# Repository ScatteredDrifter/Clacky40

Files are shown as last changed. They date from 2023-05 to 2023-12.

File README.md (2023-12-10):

# Clacky40: 

Yet another replacement Board for the Daisy40. 
Running with a RP2040, adapted from elmos:Dizzy40

--- 
## Status:
- PCB tested, _Vial support available_, working
- compatible with Case!
- minor issue with footprint fixed, pcb is fully functional now

## Features:
- RP2040 
- _(TODO) ZMK support_
- VIAL / QMK support
- supports two encoders
- additional layout options
- additional pinouts for additional LEDS ( 5V+, GND, GPIO)

--- 

## Layouting:
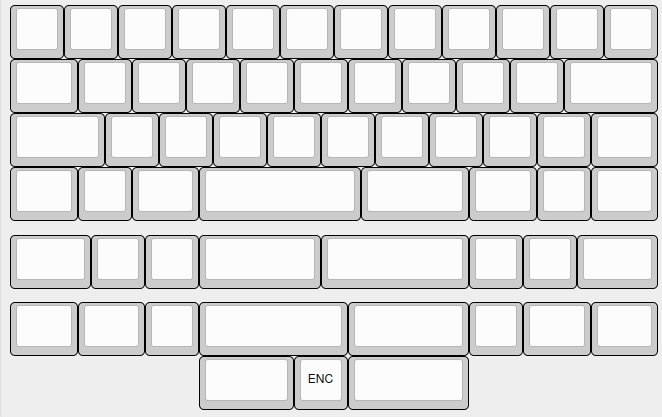
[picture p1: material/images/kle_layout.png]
image of available layouts


## Firmware:
pre-compiled file for vial can be found in the **"/firmware"** section.
To enter the bootloader - which is necessary in order to flash a new firmware - press both buttons on the back while its plugged into your computer. It should show up as a regular usb-stick in your file explorer now and you can drag the .utf onto this usb-stick. Once done it will restart and use your newly flashed firmware!
You can confirm that everything went well by opening Vial or listing the available usb-devices (`lsusb` in lin)

**Alternatively** one could download my fork of vial-qmk [here](https://github.com/ScatteredDrifter/vial-qmk) and compile the firmware themself.
For that you will have to:
1. have set up qmk and be ready to compile and flash. ( See `qmk setup` or consult [the qmk tutorial](https://docs.qmk.fm/#/newbs))
2. **find my** keyboards,  under `../keyboards/scattereddrifter/*` and choose **clacky40**.
3. make your changes
4. compile with `qmk compile --kb scattereddrifter/clacky40 --km yourKeyMap` 

### Getting PCBs:

Gathering PCBs is fairly simple, at least with JLCPCB ( which I usually default to and base my workflow around).
under the `/production/*` section you can find a zip-archive that contains the required gerber for the newest version of this board. 

1. upload the `*_gerber.zip` to JLCs website and select your prefered parameters ( pcb color, etc)
2. select "assembly" if you want to order this pcb **fully assembled with MCU etc** 
3. you will now have to supply the _positions_ and _bom (bill of materials)_ as **.csv**. You can find those at `/production/assembly/*` and should then upload them accordingly.
4. check whether every component is selected in the BOM-overview ( pinouts like J1 to Jx or keyswitches are listed but dont require any component, you can leave them out so to say)
5. finally confirm placement of the selected components ( usually I have them correct them anyway so its more or less a _sanity check_)
6. you have now ordered pcbs successfully

## Images:

### | Images of PCB | 

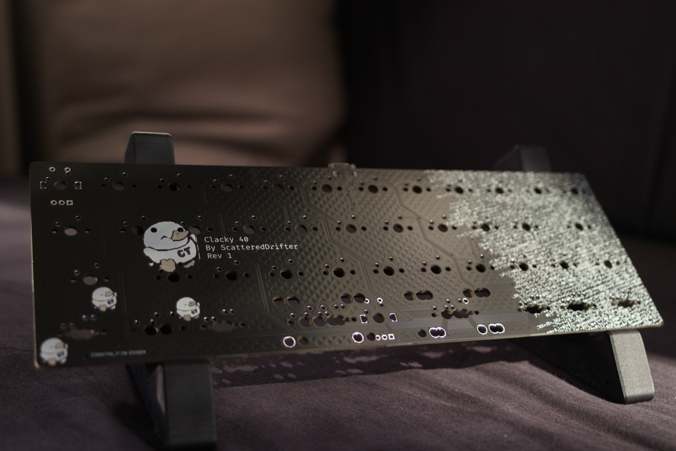
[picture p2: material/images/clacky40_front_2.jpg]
front image of pcb


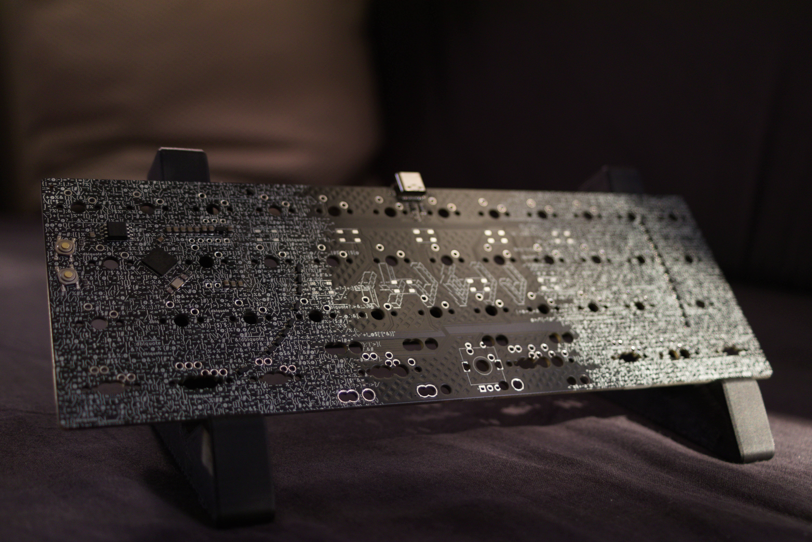
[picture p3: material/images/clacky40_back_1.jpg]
back image of pcb


### | Built with Daisy40-Case from KPrepbulic | 

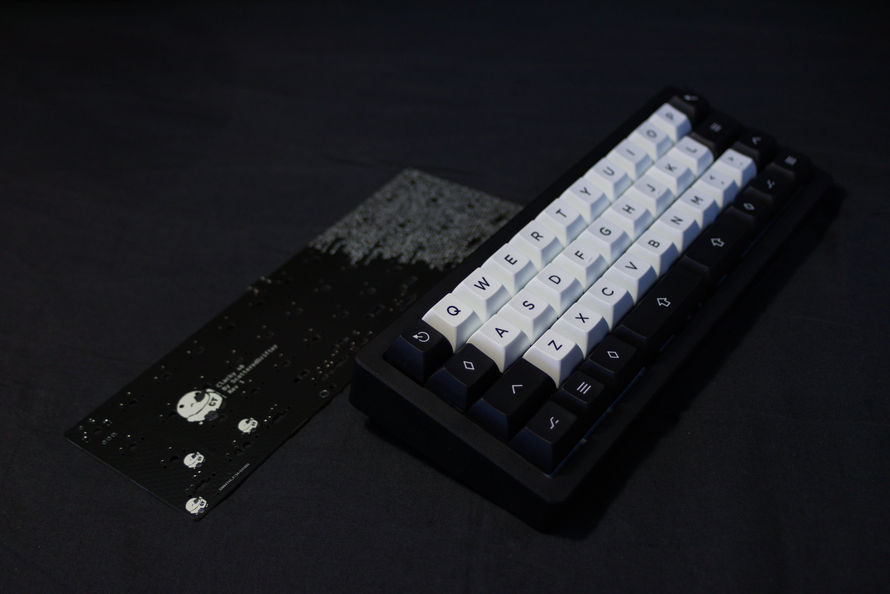
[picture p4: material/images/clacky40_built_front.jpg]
built keyboard with pcb in the back


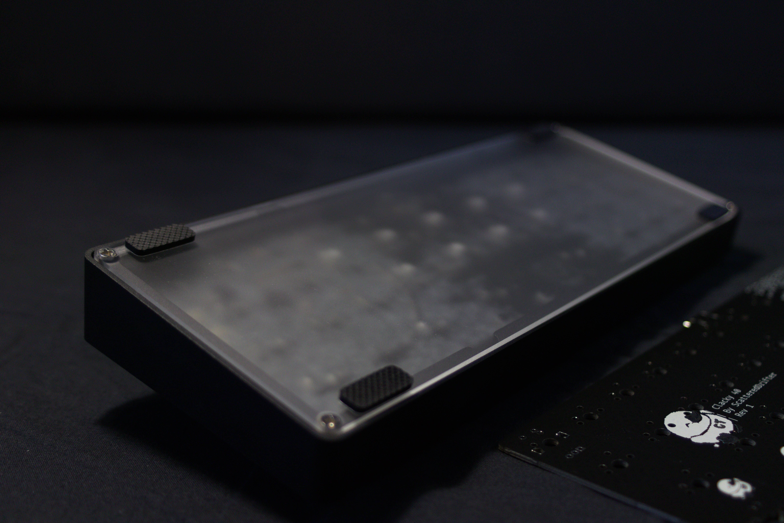
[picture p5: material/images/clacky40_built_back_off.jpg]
built keyboard backside


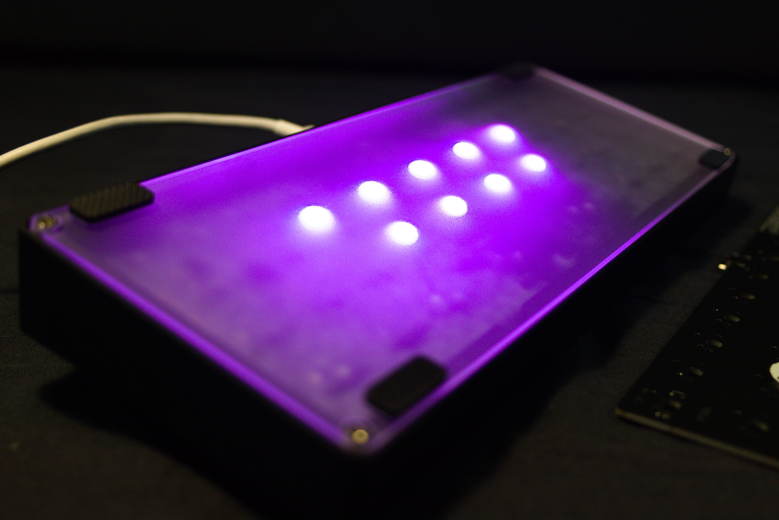
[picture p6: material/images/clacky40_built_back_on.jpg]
built keyboard backside with LEDS on


---

This work is licensed under a
[Creative Commons Attribution-NonCommercial-ShareAlike 4.0 International License][cc-by-nc-sa].

[][cc-by-nc-sa]

[cc-by-nc-sa]: http://creativecommons.org/licenses/by-nc-sa/4.0/
[cc-by-nc-sa-image]: https://licensebuttons.net/l/by-nc-sa/4.0/88x31.png
[cc-by-nc-sa-shield]: https://img.shields.io/badge/License-CC%20BY--NC--SA%204.0-lightgrey.svg

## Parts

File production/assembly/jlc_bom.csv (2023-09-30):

Comment | Designator | Footprint | LCSC
10u | C1,C4,C17 | Capacitor_SMD:C_0805_2012Metric | C91245
22pf | C2,C3 | Capacitor_SMD:C_0805_2012Metric | C1804
100n | C5,C6,C7,C9,C11,C12,C13,C14 | Capacitor_SMD:C_0805_2012Metric | C49678
1u | C8,C10 | Capacitor_SMD:C_0805_2012Metric | C28323
BAV70 | D17,D18,D19,D20,D21,D22,D23,D24,D25,D26,D27,D28,D29,D30,D31,D32,D33,D34,D35,D36,D37,D38,D39 | Package_TO_SOT_SMD:SOT-23
RotaryEncoder_Switch | ENC1,ENC2 | Keebio-Parts:RotaryEncoder_Alps_EC11E-Switch_Vertical_H20mm
polyfuse | F0 | Fuse:Fuse_1206_3216Metric | C69688
USB_C_Receptacle_USB2.0 | J0 | Connector_USB:USB_C_Receptacle_HRO_TYPE-C-31-M-12 | C165948
BREAKOUT | J1 | Connector_PinSocket_2.54mm:PinSocket_1x05_P2.54mm_Vertical
Conn_01x03_Male | J2 | Connector_PinSocket_2.54mm:PinSocket_1x03_P2.54mm_Vertical
Screw_Terminal_01x02 | J3,J5,J6,J7,J8 | marbastlib-mx:STAB_MX_P_2u
Breakout 1.1v | J4 | Connector_PinSocket_2.54mm:PinSocket_1x02_P2.54mm_Vertical
KEYSW | K1,K2,K3,K4,K5,K6,K7,K8,K9,K10,K11,K12,K13,K14,K15,K16,K17,K18,K19,K20,K21,K22,K23,K24,K25,K26,K27,K28,K29,K30,K31,K32,K33,K34,K35,K36,K37,K38,K39,K40,K41,K42,K45,K46,K49,K50,K51,K52,K53,K54,K55,K56,K57,K58,K59 | marbastlib-mx:SW_MX_1u
1k | R1,R5 | Resistor_SMD:R_0805_2012Metric | C115316
27 | R3,R4 | Resistor_SMD:R_0805_2012Metric | C104170
5.1k | R6,R7 | Resistor_SMD:R_0805_2012Metric | C27834
10k | R8 | Resistor_SMD:R_0805_2012Metric | C115309
WS2812B | RGB1,RGB2,RGB3,RGB4,RGB5,RGB6,RGB7,RGB8,RGB9 | kbd:LED_WS2812B-PLCC4 | C965555
RESET | SW0 | Keebio-Parts:SW_SPST_TL3342 | C2886894
RESET | SW2 | Keebio-Parts:SW_SPST_TL3342 | C2886894
W25Q128JVS | U2 | Package_SO:SOIC-8_5.23x5.23mm_P1.27mm | C97521
RP2040 | U3 | RP2040:RP2040-QFN-56 | C2040
XC6206P Smaller footprint, less mA ~.5 | U4 | Package_TO_SOT_SMD:SOT-23 | C347376
SRV05-4 | U44 | Package_TO_SOT_SMD:SOT-23-6 | C85364
12MHZ Crystal | Y0 | Crystal:Crystal_SMD_3225-4Pin_3.2x2.5mm | C9002

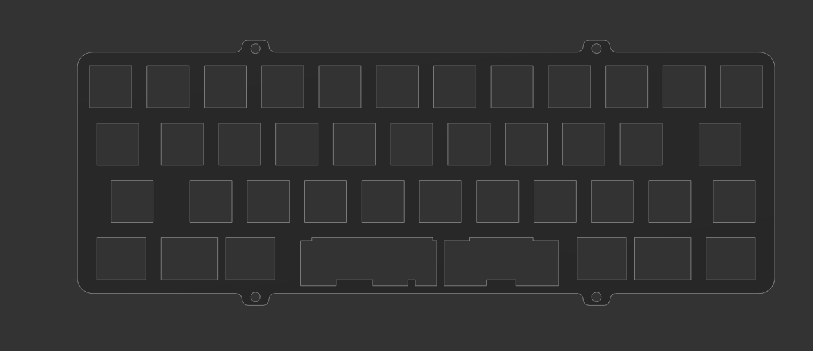
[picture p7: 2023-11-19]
material/images/imageplateclacky40.PNG

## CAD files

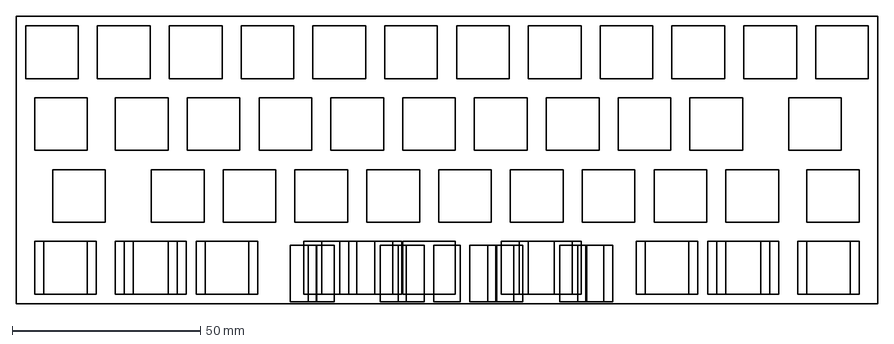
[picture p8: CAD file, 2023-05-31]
material/outlines/base_plate.dxf
228.6 x 76.2 mm

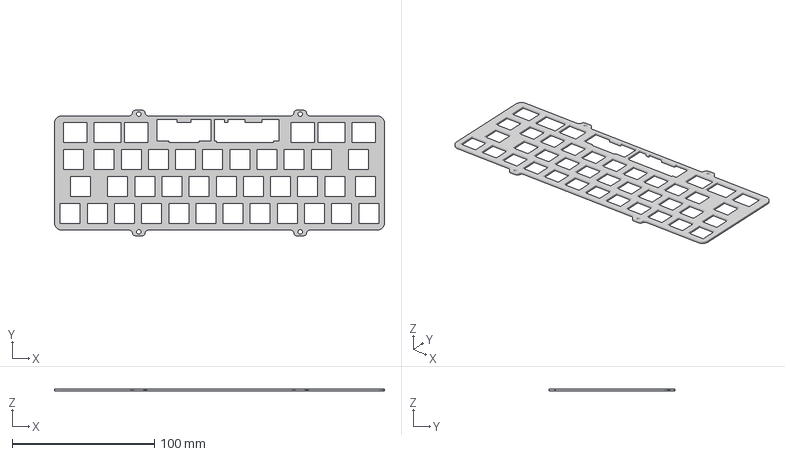
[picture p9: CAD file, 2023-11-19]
plateclacky16mm.3mf
231.6 x 88.2 x 1.60 mm

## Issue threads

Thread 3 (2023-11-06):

Rev V¹: Key [2,1] is pressed constantly

ScatteredDrifter, 2023-11-06:
The key close / even overlapped / by the largest duck on the front side **is constantly** pressed.

This is caused by the footprint itself as it spans a net across its feet which **accidentally interconnected** both switch pins.

For V¹ theres an easy fix for this as they only have a small intersection one could cut with a small knife.

Belows screenshot will show where to set a small cut **at the front** of the pcb:
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

Closed 2023-11-06.

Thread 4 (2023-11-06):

outdated README

ScatteredDrifter, 2023-11-06:
Considering that the first prototypes were ordered and are ready  to use I ought to update the following information:
- images of PCB
- link to firmware or upload compiled firmware for vial
- list fix for Rev V¹ before fix
- information on how to order

ScatteredDrifter, 2023-12-10:
resolved in deab6a9

Closed 2023-12-10.

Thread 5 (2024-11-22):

Is there another way to reset the bootloader?

hyezo, 2024-11-22:
Hello.
First of all, thank you for sharing your custom Daisy PCB.
I was able to make a PCB according to your repository.

However, even if I press the two buttons with the USB plugged in, there is no response.
I have tested it on Macos and windows.
There are a few suspicious circumstances.

1. When manufacturing the part, the reset button part was not in stock.
So I replaced it with a more pressure demanding (450gf) part. Is this a problem?
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

2. I excluded the encoder, RGB and some parts that start with J. Does that matter?

3. RP2040 chip starting position.
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

I would really appreciate your reply 🙏

Closed 2024-11-25.

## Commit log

2023-09-30 updated pcb, routing and created silkscreen
    [RP2040_tmp.kicad_pcb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]
2023-11-01 repositioned kle, images and plate files to "material"
    [base_plate.dxf, daisy40_plate.dxf, plate-2023-05-01T19 39 07.864Z.dxf]
2023-11-06 pcb fixed, resolves #3
2023-11-19 update readme, include images and status update
    [plateclacky16mm.3mf]
2023-12-13 update firmware, enables led underglow

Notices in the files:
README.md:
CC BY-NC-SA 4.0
